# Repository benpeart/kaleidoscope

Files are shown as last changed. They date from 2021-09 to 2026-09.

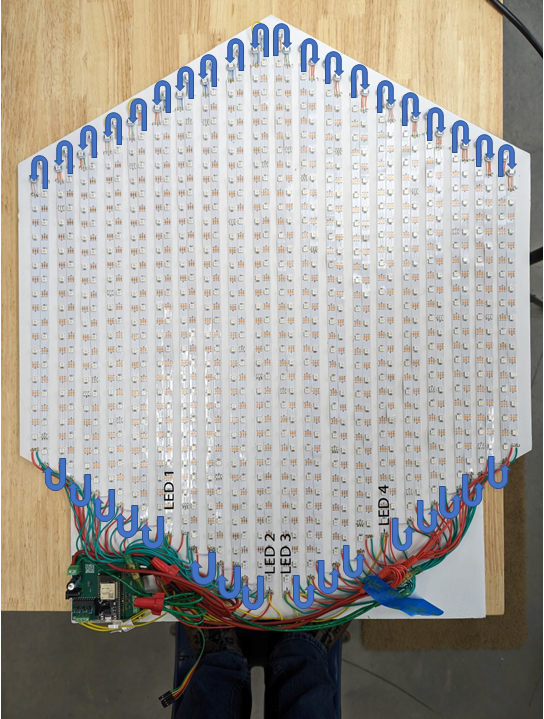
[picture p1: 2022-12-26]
images/Wiring diagram for LED strips.png

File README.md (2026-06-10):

# Kaleidoscope
A Digital Kaleidoscope maker project.

## Developer Workflow

Build the [env:release] image then flash the entire image (nvs, otadata, safeboot, app) with the command:

```
cd %userprofile%\.platformio\packages\tool-esptoolpy
python .\esptool.py write_flash 0x0 \src\kaleidoscope\.pio\build\release\firmware.factory.bin
```

Then connect to the KaleidoscopeAP with your phone and setup your WiFi credentials. Save and reboot and it will connect to your wifi with the name "kaleidoscope.local." Open http://kaleidoscope.local and configure the UI of the Kaleidoscope (mode, clock, reflection, brightness, speed, clock color).

Subsequent updates of the app partition can be updated using platform.io and the [env:release-ota] or [env:debug-ota] environments. You can also click the 'cloud upload' icon in the bottom left of the Kaleidoscope UI, refresh the page to load the safeboot ui, then drag/drop the firmware.bin file you want to flash

## User Workflow

### First Time Setup
1. Device starts without saved WiFi credentials
2. Fails to connect (timeout after 20 seconds)
3. Enters AP mode with SSID: `kaleidoscopeAP`
4. User connects their phone/computer to `kaleidoscopeAP`
5. Captive portal automatically opens (or user goes to `http://192.168.4.1`)
6. Configure WiFi SSID and password
7. Device saves credentials and reconnects
8. Kaleidoscope page becomes accessible at device's IP or `kaleidoscope.local`

### Subsequent Starts
1. Device boots and loads saved WiFi credentials
2. Connects to WiFi automatically
3. Kaleidoscope page immediately available

### OTA Update Process
1. User clicks cloud upload icon on the kaleidoscope page
2. Device reboots with SafeBoot partition active (refresh page to see)
3. Use the safeboot UI page to upload the new firmware
4. Device restarts with new firmware
5. If failure: SafeBoot recovery mechanism allows fallback

## REST API documentation

The Kaleidoscope connects to the WiFi with the device name "kaleidoscope." The web ui and REST API can be found at http://kaleidoscope.local/. 
Alternately, check your router for the IP address.

There are four REST endpoints that make up the REST API:

1. "http://kaleidoscope/api/settings"
1. "http://kaleidoscope/api/modes"
1. "http://kaleidoscope/api/faces"
1. "http://kaleidoscope/api/drawstyles"

## 'Settings' REST API

A GET sent to the Settings endpoint will return a result that includes the following entries:
PUT will allow you to set some or all of the same values.

```
{
    "mode": "Twinkle Fox",
    "drawStyle": "Six way",
    "brightness": 4095,
    "speed": 25,
    "clockFace": "Off",
    "clockColor": "#FFFFFF"
}
```

### Mode

The mode specifies which of the available Kaleidoscope modes is currently active. This can vary as more are added or removed but currently the list of available modes includes:

```
{
    "off",
    "Kaleidoscope",
    "Plasma",
    "Ripples",
    "Twinkle Fox",
    "AA Lines",
    "Distortion Waves",
    "Rainbow",
    "Matrix",
    "Pacifica",
    "Snake",
    "Fire"
}    
```        

### drawStyle

The drawStyle controls the type of reflection style the Kaleidoscope emulates. Currently this includes:

```
{
    "Six way",
    "Twelve way",
    "Twenty four way"
}
```        

### Brightness

Brightness is treated as an adjustment to the automatic brightness as computed using the photoresister to determine
the ambient brightness of the room. Greater than zero makes it brighter than default, less than zero makes it darker than default.
The valid range is -255 (dark) to 255 (bright). The default is 0.

### Speed

The Kaleidoscope speed is a value between 0 (slow) to 255 (fast). The default is 127.
Not all modes can honor all speeds; each one is responsible for making a 'best effort.'

### clockFace

Choose what clock face (if any) is displayed.

```
{
    "Off",
    "Digital",
    "Analog"
}
```

### clockColor

A hexadecimal color is specified with: #RRGGBB, where the RR (red), GG (green) and BB (blue) hexadecimal integers specify the components of the color.

## 'Modes' REST API

A GET sent to the /api/modes endpoint will return an array of the available modes.
PUT will allow you to set some or all of the same values.

A sample result would be the following:

```
["Kaleidoscope","Plasma","Ripples","Twinkle Fox","AA Lines","Distortion Waves","Rainbow","Matrix","Pacifica","Snake","Fire"]
```

## 'Faces' REST API

A GET sent to the /api/faces endpoint will return an array of the available clock faces.
PUT will allow you to set some or all of the same values.

A sample result would be the following:

```
["Off","Digital","Analog"]
```

## 'DrawStyles' REST API

A GET sent to the /api/drawstyles endpoint will return an array of the posible draw styles.
PUT will allow you to set some or all of the same values.

A sample result would be the following:

```
["Six way","Twelve way","Twenty four way"]
```

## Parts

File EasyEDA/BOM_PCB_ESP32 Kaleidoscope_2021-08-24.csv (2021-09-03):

ID | Name | Designator | Footprint | Quantity | Manufacturer Part | Manufacturer | Supplier | Supplier Part | Price | Pins | 3DModel | JLCPCB Part Class | LCSC Assembly | Paste Type | Contributor | SMT Type | description | link
1 | 10K | R5,R6,R7,R8,R9,R10,R11 | R0603 | 7 | ARG03FTC1002 | Viking Tech | LCSC | C217687 | 0.007 | 2 | R0603_L1.6-W0.8-H0.8 | Extended Part |  |  | LCSC |  |  | https://www.mouser.in/datasheet/2/447/PYu_RT_1_to_0_01_RoHS_L_11-1669912.pdf
2 | 1000uF | C1 | CAP-TH_BD10.0-P5.00-D1.0-FD | 1 | 25YXJ1000M10X20 | Rubycon | LCSC | C88720 | 0.271 | 2 | CAP-TH_D10.0-H16.0-P5.00 | Extended Part |  |  | 官方封装库 |  |  | https://item.szlcsc.com/44833.html
3 | 10nF | C2,C3,C4,C5,C6,C7 | CAP-TH_L5.0-W2.5-P2.54-D0.7 | 6 | CC1H103ZA1AD3F4D10MF | Dersonic | LCSC | C254082 | 0.013 | 2 | CAP-TH_BD5.0-W2.5-P2.54 | Extended Part |  |  | LCSC |  | Indicating Instrument; 2 Leads | https://lcsc.com/product-detail/Ceramic-Disc-Capacitors_Made-in-China-CS1F5-6Y5V1A104Z_C9306.html
4 | 470K | LED1,LED2,LED3,LED4 | R1206 | 4 | RMCF1206JT470K | Stackpole Elec | LCSC | C237785 | 0.012 | 2 | R1206_L3.2-W1.6-H0.6 | Extended Part |  |  | LCSC |  |  | https://item.szlcsc.com/311874.html
5 | SN74HCT245N | BUFFER1 | DIP-20_L26.8-W6.4-P2.54-LS7.6-BL | 1 | SN74HCT245N | Texas Instruments | LCSC | C133640 | 0.402 | 20 | DIP-20_L26.2-W6.4-H5.4-LS7.62-P2.54 |  |  |  | LCSC |  |  | https://item.szlcsc.com/348321.html
6 | WJ124-3.81-4P | P1 | CONN-TH_4P-P3.81_KF124-3.81-4P | 1 | WJ124-3.81-4P | ReliaPro | LCSC | C69809 | 0.348 | 4 | CONN-TH_WJ3.81-LI-4P-124 | Extended Part |  |  | 立创EDA官方封装库 |  |  | https://item.szlcsc.com/70903.html
7 | WJ128V-5.0-2P | P2 | CONN-TH_2P-P5.00_WJ128V-5.0-2P | 1 | WJ128V-5.0-2P | ReliaPro | LCSC | C8269 | 0.115 | 2 | CONN-TH_2P-L10.0-W10.3-H14.1-P5.0 | Extended Part |  |  | 立创EDA官方封装库 |  |  | https://item.szlcsc.com/8761.html
8 | RE-H022TD-1190 (LF)(SN) | PHOTO | HDR-TH_2P-P2.54-V | 1 | - | JST Sales America | LCSC | C160332 | 0.084 | 2 | HDR-M-2.54_1x2 |  | Yes | expand | LCSC | Extend |  | https://item.szlcsc.com/366904.html
9 | DC-470-2.1GP | DC_5V | DC-IN-TH_DC-470-2.1GP | 1 | DC-470-2.1GP | GANGYUAN | LCSC | C194407 | 0.055 | 3 | DC-IN-TH_L14.0-W8.9-H10.9 |  |  |  | 立创EDA官方封装库 |  |  | https://so.szlcsc.com/global.html?c=&k=C194407
10 | ESP32 - WROOM-32U - DevKit 38pins | U1 | ESP32 - WROOM-32U - DEVVKIT 38PIN | 1 |  |  | Sparkfun |  |  | 38 |  |  |  |  | chrisrisse
11 | WJ124-3.81-5P-14-00A | LEFT_ENCODER,RIGHT_ENCODER | CONN-TH_5P-P3.81_KF124-3.81-5P | 2 | WJ124-3.81-5P-14-00A | ReliaPro | LCSC | C72336 | 0.328 | 5 | CONN-TH_5P-P3.81_KF124-3.81-5P |  |  | expand | 立创EDA官方封装库 |  |  | https://item.szlcsc.com/70903.html

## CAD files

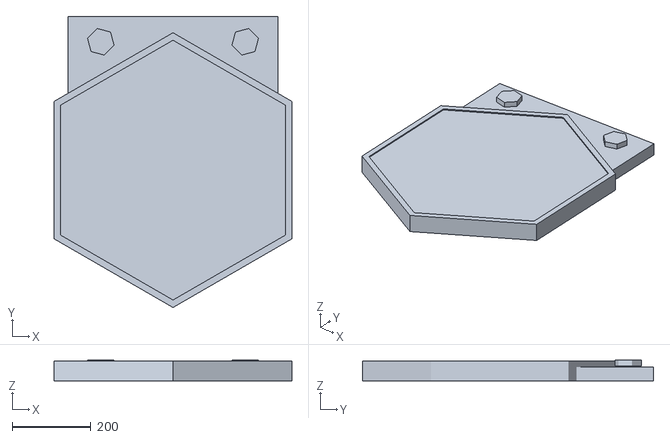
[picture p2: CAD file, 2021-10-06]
3dmodels/Kaleidoscope.stl
604.8 x 739.7 x 53.1

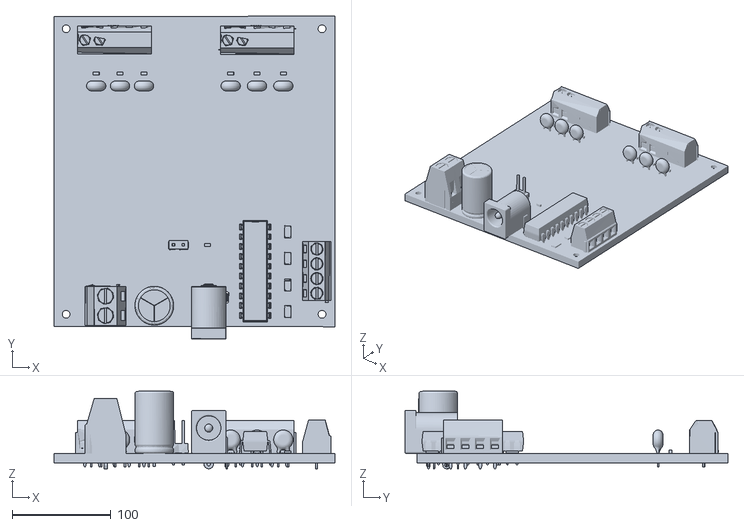
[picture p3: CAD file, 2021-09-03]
EasyEDA/OBJ_PCB_ESP32 Kaleidoscope.obj
285.2 x 327.6 x 78.7

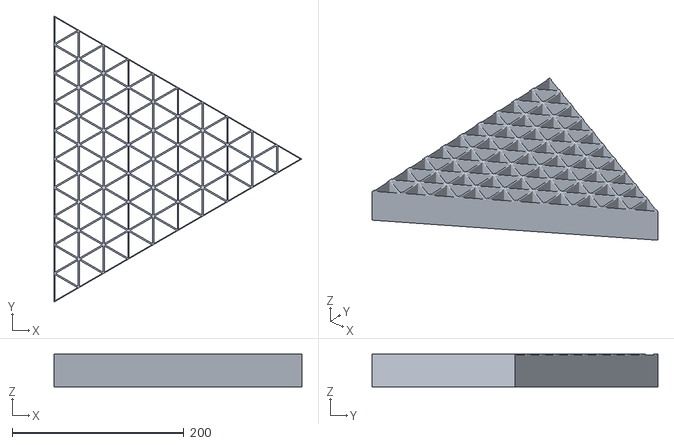
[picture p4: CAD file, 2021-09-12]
3dmodels/Honeycomb.stl
288.7 x 333.3 x 38.1

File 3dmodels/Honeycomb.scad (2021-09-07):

fudge=0.004;

// honeycomb dimensions
stroke = 2.4;
notch_width = 21;
notch_depth = 1;
distance_apart = 33 + 1/3;
wall_height = 38.1; // 1 1/2"
triangle_height = (distance_apart * sqrt(3)) / 2;
triangle_zaxis_offset=-fudge/2;
num_rings = 10;
radius = distance_apart * num_rings;

honeycomb();

module honeycomb()
{
    difference()
    {
        // draw the hexagon
        rotate(30) cylinder(h=wall_height, r=radius, $fn=6);
        
        // remove notches for the led strips
        for (i = [num_rings / 2 - 1:-1:(-2 * num_rings) + (num_rings / 2)]) // draws the square
        {
            orgin = [triangle_height * -10, distance_apart * i  + (triangle_height - notch_width) / 2, wall_height - notch_depth];
                                                                               //the + 1 is needed to finish the etch
            translate(orgin) rotate(30)cube([distance_apart * (num_rings * 2 + 1), notch_width,notch_depth]); 
        }
        
        // remove the triangles for the lights
        for (y = [num_rings:-1:-num_rings]) 
        {
            for (x = [-num_rings:2:num_rings])
            {
                translate([x * triangle_height + (triangle_height * (2/3)), y * distance_apart, triangle_zaxis_offset]) rotate(60) 
                    cylinder(h=wall_height+fudge, r=(triangle_height* 2/3) - stroke/2, $fn=3);
                translate([x * triangle_height - (triangle_height * (2/3)), y * distance_apart, triangle_zaxis_offset]) rotate(0)
                    cylinder(h=wall_height+fudge, r=(triangle_height* 2/3) - stroke/2, $fn=3);
                
                translate([(x+1) * triangle_height + (triangle_height * (2/3)), (y) * distance_apart + distance_apart / 2, triangle_zaxis_offset]) rotate(60) 
                    cylinder(h=wall_height+fudge, r=(triangle_height* 2/3) - stroke/2, $fn=3);
                translate([(x+1) * triangle_height - (triangle_height * (2/3)), (y) * distance_apart + distance_apart / 2, triangle_zaxis_offset]) rotate(0)
                    cylinder(h=wall_height+fudge, r=(triangle_height* 2/3) - stroke/2, $fn=3);        
            }
        }

        // shrink the size for testing purposes
        translate([0,0,-1]) rotate(60) cube([1000,1000,100]);
        translate([0,0,-1]) rotate(120) cube([1000,1000,100]);
        translate([0,0,-1]) rotate(180) cube([1000,1000,100]);
        translate([0,0,-1]) rotate(-0) cube([1000,1000,100]);
        translate([0,0,-1]) rotate(-30) cube([1000,1000,100]);
        /*
        translate([0,-8 * distance_apart,-1]) rotate(30) cube([1000,1000,100]);
        translate([0,-6 * distance_apart,-1]) rotate(-30) cube([1000,1000,100]);
        */

    }
}

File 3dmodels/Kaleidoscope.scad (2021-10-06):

fudge=0.004;

// honeycomb dimensions
stroke = 3.2;   // this needs to be double the wall width you actually want when printing, not sure why...
                // the printer can print in increments of 0.4 mm so we make the outside walls 0.8mm and the inside
                // walls 1.6mm.
notch_width = 21;
notch_depth = 1;
distance_apart = 33 + 1/3;
wall_height = 38.1; // 1 1/2"
triangle_height = (distance_apart * sqrt(3)) / 2;
triangle_zaxis_offset=-fudge/2;
num_rings = 10;
radius = distance_apart * num_rings;

// diffuser dimensions
diffuser_thickness = 3.175; // 1/8 inch

// backboard dimensions
backboard_thickness = 6.35; // 1/4 inch

// side wall dimensions
side_wall_thickness = 19.05;// 3/4 inch
side_wall_height = backboard_thickness + wall_height + (2 * diffuser_thickness);

// chin dimensions
chin_width = (radius + side_wall_thickness) * sin(60) * 2 - (4 * side_wall_thickness);
chin_depth = side_wall_thickness + wall_height;
chin_wall_height = 31.75; // 1 1/4 inch

// knob dimensions
knob_height = 15;
knob_radius = 35;


//
// Draw all the component pieces
//
color("yellow") backboard();
color("blue") honeycomb_sidewall();
//color("black") honeycomb();
color("gray", 0.25) diffuser();

color("brown") chin_sidewall();
//color("green") translate([-559 - side_wall_thickness, -770, backboard_thickness]) rotate(90) resize([72.8, 80.4, 25]) import("OBJ_PCB_ESP32 Kaleidoscope.stl");
color("brown", 0.5) chin_top();

color("silver") translate([chin_width / 4 + 50, radius - chin_depth + 50, chin_wall_height + backboard_thickness]) rotate(15) cylinder(h=knob_height, r=knob_radius, $fn=6);
color("silver") translate([-(chin_width / 4 + 50), radius - chin_depth + 50, chin_wall_height + backboard_thickness]) rotate(45) cylinder(h=knob_height, r=knob_radius, $fn=6);


module backboard()
{
    union()
    {
        // draw the hexagon
        rotate(30)
        cylinder(h=backboard_thickness, r=(radius + diffuser_thickness), $fn=6);
        
        // draw the chin
        translate([side_wall_thickness - chin_width / 2 - diffuser_thickness, chin_depth + side_wall_thickness, 0])
        cube([chin_width - (2 * side_wall_thickness) + (2 *  + diffuser_thickness), radius - (2 * side_wall_thickness) + diffuser_thickness, backboard_thickness]);
    }
}

module diffuser()
{
    // draw the diffuser hexagon
    rotate(30)
    translate([0, 0, backboard_thickness + wall_height]) 
    cylinder(h=diffuser_thickness, r=(radius + diffuser_thickness), $fn=6);
}

module honeycomb_sidewall()
{
    rotate(30)
    difference()
    {
        // draw the expanded hexagon
        cylinder(h=side_wall_height, r=(radius + side_wall_thickness - diffuser_thickness), $fn=6);

        // now remove the face of the honeycomb leaving a lip to hold the contents (diffuser + honeycomb + backboard)
        translate([0, 0, -fudge / 2]) 
        cylinder(h=side_wall_height + fudge, r=radius - diffuser_thickness, $fn=6);

        // now remove bottom of the honeycomb to leave room for the diffuser, honeycomb and backboard
        translate([0, 0, -diffuser_thickness]) 
        cylinder(h=side_wall_height, r=radius, $fn=6);
        
        // remove the chin in two pieces to leave a support
        rotate(-30)
        translate([-chin_width / 2, chin_depth, -fudge/2]) 
        cube([chin_width / 2 - 10, radius, chin_wall_height + diffuser_thickness + fudge]);
        rotate(-30)
        translate([10, chin_depth, -fudge/2]) 
        cube([chin_width / 2 - 10, radius, chin_wall_height + diffuser_thickness + fudge]);
    }
}

module chin_sidewall()
{
    difference()
    {
        // draw the chin
        translate([-chin_width / 2, chin_depth, 0]) 
        cube([chin_width, radius, chin_wall_height]);
        
        // remove the chin insides
        translate([-chin_width / 2 + side_wall_thickness, chin_depth, - fudge / 2]) 
        cube([chin_width - (2 * side_wall_thickness), radius - side_wall_thickness, chin_wall_height + fudge]);

        // remove the expanded hexagon
        rotate(30) translate([0, fudge / 2, 0]) 
        cylinder(h=side_wall_height + fudge, r=radius, $fn=6);
        
        // remove a notch for the backboard
        backboard();
    }
}

module chin_top()
{
    difference()
    {
        // draw a lid for the chin
        translate([-chin_width / 2, chin_depth, chin_wall_height]) 
        cube([chin_width, radius, diffuser_thickness]);
        
        // remove the expanded hexagon
        rotate(30) translate([0, fudge / 2, 0]) 
        cylinder(h=side_wall_height + fudge, r=radius, $fn=6);
    }
}

module honeycomb()
{
    translate([0, 0, backboard_thickness]) 
    difference()
    {
        // draw the hexagon
        rotate(30) cylinder(h=wall_height, r=radius, $fn=6);
        
        // remove notches for the led strips
        for (i = [num_rings / 2 - 1:-1:(-2 * num_rings) + (num_rings / 2)]) // draws the square
        {
            orgin = [triangle_height * -10, distance_apart * i  + (triangle_height - notch_width) / 2, wall_height - notch_depth];
                                                                               //the + 1 is needed to finish the etch
            translate(orgin) rotate(30)cube([distance_apart * (num_rings * 2 + 1), notch_width,notch_depth]); 
        }
        
        // remove the triangles for the lights
        for (y = [num_rings:-1:-num_rings]) 
        {
            for (x = [-num_rings:2:num_rings])
            {
                translate([x * triangle_height + (triangle_height * (2/3)), y * distance_apart, triangle_zaxis_offset]) rotate(60) 
                    cylinder(h=wall_height+fudge, r=(triangle_height* 2/3) - stroke/2, $fn=3);
                translate([x * triangle_height - (triangle_height * (2/3)), y * distance_apart, triangle_zaxis_offset]) rotate(0)
                    cylinder(h=wall_height+fudge, r=(triangle_height* 2/3) - stroke/2, $fn=3);
                
                translate([(x+1) * triangle_height + (triangle_height * (2/3)), (y) * distance_apart + distance_apart / 2, triangle_zaxis_offset]) rotate(60) 
                    cylinder(h=wall_height+fudge, r=(triangle_height* 2/3) - stroke/2, $fn=3);
                translate([(x+1) * triangle_height - (triangle_height * (2/3)), (y) * distance_apart + distance_apart / 2, triangle_zaxis_offset]) rotate(0)
                    cylinder(h=wall_height+fudge, r=(triangle_height* 2/3) - stroke/2, $fn=3);        
            }
        }
        // shrink the size for testing purposes
        translate([0,0,-1]) rotate(60) cube([1000,1000,100]);
        translate([0,0,-1]) rotate(120) cube([1000,1000,100]);
        translate([0,0,-1]) rotate(180) cube([1000,1000,100]);
        translate([0,0,-1]) rotate(-0) cube([1000,1000,100]);
        translate([0,0,-1]) rotate(-30) cube([1000,1000,100]);
/*
        translate([0,-4 * distance_apart,-1]) rotate(30) cube([1000,1000,100]);
        translate([0,-4 * distance_apart,-1]) rotate(-30) cube([1000,1000,100]);
*/
    }
}

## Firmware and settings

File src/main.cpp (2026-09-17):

#include "main.h"
#include "debug.h"
#include "settings.h"
#include "modes.h"
#include <math.h>
#include "DoubleResetDetector.h"
#include <MycilaSystem.h>

#ifdef BOUNCE
// https://github.com/thomasfredericks/Bounce2
#include <Bounce2.h>
#endif // BOUNCE

#ifdef WIFI
#include "WiFiHelpers.h"

#ifdef REST
#include <AsyncJson.h>
#endif // REST

#ifdef TIME
#include "RealTimeClock.h"
#endif // TIME

#ifdef WEATHER
#include "weather.h"
#endif // WEATHER

#endif // WIFI

//
// GLOBAL PIN DECLARATIONS -------------------------------------------------
//
#ifdef PHOTOCELL
#define PHOTOCELL_PIN 33
#endif

#ifdef ENCODER
// Change these pin numbers to the pins connected to your encoder.
#define ENCODER_CLK_PIN_LEFT 4
#define ENCODER_DT_PIN_LEFT 16
#define ENCODER_CLK_PIN_RIGHT 5
#define ENCODER_DT_PIN_RIGHT 18
#endif

#ifdef BOUNCE
// Change these pin numbers to the button pins on your encoder.
#define ENCODER_SW_PIN_LEFT 17
#define ENCODER_SW_PIN_RIGHT 19
#endif // BOUNCE

// setup our LED strips for parallel output using FastLED
#ifdef JTAG
// JTAG uses GPIO12-GPIO15 so we can't use GPIO14 for an LED strip. Redefine it to use an unused GPIO
// so that we can debug even though we can't see the output of LED_STRIP_PIN_1 when mounted on the PCB.
// TODO: when we rev the PCB, use a different GPIO for LED_STRIP_PIN_1
#define LED_STRIP_PIN_1 32
#else
#define LED_STRIP_PIN_1 14
#endif
#define LED_STRIP_PIN_2 27
#define LED_STRIP_PIN_3 26
#define LED_STRIP_PIN_4 25
#define LED_TYPE WS2812B
#define COLOR_ORDER GRB

//
// Global variables  -------------------------------------------------
//

DoubleResetDetector drd(&preferences);

#ifdef BOUNCE
// Instantiate Button objects from the Bounce2 namespace
Bounce2::Button leftButton = Bounce2::Button();
Bounce2::Button rightButton = Bounce2::Button();
#define DEBOUNCE_MS 15 // Button debounce time, in milliseconds
#endif

#ifdef ENCODER
// Instantiate rotary encoder knob objects
ESP32Encoder knobRight;
ESP32Encoder knobLeft;
#endif

//
// BRIGHTNESS helpers -------------------------------------------------
//

// true if the brightness has been changed via the REST API and needs to be reflected immediately
volatile bool brightness_dirty = false;

// Tracks the next Unix timestamp (epoch seconds) when brightness needs recalculation.
// Checking once every 15 to 30 seconds only while in twilight, and setting the next wake
// time to the exact start of the next twilight when outside it, drops checks from ~28,000 down to
// roughly ~250 per day.
static time_t nextSolarCheckEpoch = 0;

// Transition window duration in minutes (e.g., 60 mins total: 30 mins before, 30 mins after dawn/dusk)
#define TWILIGHT_TRANSITION_MINUTES 60.0f

#define KNOB_INCREMENT (MAX_BRIGHTNESS / 20) // brightness range / number of pulses in one rotation of rotary encoder

// Returns a smooth multiplier from 0.5 (full night) to 1.0 (full day) and schedules next check
float getSolarBrightnessScale()
{
#if defined(TIME)
  time_t now = time(nullptr);
  if (now < 100000)
  {
    // Fallback if clock is not synchronized yet; recheck in 10s
    nextSolarCheckEpoch = now + 10;
    return 1.0f;
  }

  struct tm local_tm;
  struct tm utc_tm;
  localtime_r(&now, &local_tm);
  gmtime_r(&now, &utc_tm);

  int N = local_tm.tm_yday + 1;

  // Solar declination (radians)
  float declination = 0.4093f * sin(2.0f * M_PI * (284 + N) / 365.0f);
  float latRad = currentLatitude * (M_PI / 180.0f);

  // Hour angle for standard zenith
  float cosOmega = -tan(latRad) * tan(declination);

  if (cosOmega >= 1.0f)
  {
    // Polar night: check again in an hour
    nextSolarCheckEpoch = now + 3600;
    return 0.5f;
  }
  if (cosOmega <= -1.0f)
  {
    // Midnight sun: check again in an hour
    nextSolarCheckEpoch = now + 3600;
    return 1.0f;
  }

  float omega = acos(cosOmega) * (180.0f / M_PI);

  // Solar noon adjusted for UTC offset
  time_t local_sec = mktime(&local_tm);
  time_t utc_sec = mktime(&utc_tm);
  float gmtOffsetHours = (float)difftime(local_sec, utc_sec) / 3600.0f;
  float solarNoon = 12.0f - (currentLongitude / 15.0f) + gmtOffsetHours;

  float dawnHour = solarNoon - (omega / 15.0f);
  float duskHour = solarNoon + (omega / 15.0f);

  // Local time in fractional hours
  float currentHour = local_tm.tm_hour + (local_tm.tm_min / 60.0f) + (local_tm.tm_sec / 3600.0f);

  float halfWindowHours = (TWILIGHT_TRANSITION_MINUTES / 60.0f) / 2.0f;
  float dawnStart = dawnHour - halfWindowHours;
  float dawnEnd = dawnHour + halfWindowHours;
  float duskStart = duskHour - halfWindowHours;
  float duskEnd = duskHour + halfWindowHours;

  float dayFactor = 0.0f;

  if (currentHour >= dawnEnd && currentHour < duskStart)
  {
    // Full daylight: schedule wake-up exactly when dusk transition begins
    dayFactor = 1.0f;
    float secondsUntilDusk = (duskStart - currentHour) * 3600.0f;
    nextSolarCheckEpoch = now + (time_t)max(1.0f, secondsUntilDusk);
  }
  else if (currentHour >= duskEnd || currentHour < dawnStart)
  {
    // Full night: schedule wake-up exactly when dawn transition begins
    dayFactor = 0.0f;
    float hoursUntilDawn = (currentHour < dawnStart) ? (dawnStart - currentHour)
                                                     : (24.0f - currentHour + dawnStart);
    nextSolarCheckEpoch = now + (time_t)max(1.0f, hoursUntilDawn * 3600.0f);
  }
  else
  {
    // In active twilight transition: step every 15s (captures single-unit changes at max slope)
    nextSolarCheckEpoch = now + 15;

    if (currentHour < dawnEnd)
    {
      // Dawn window: ramping UP (night -> day)
      float progress = (currentHour - dawnStart) / (2.0f * halfWindowHours);
      dayFactor = 0.5f * (1.0f - cos(constrain(progress, 0.0f, 1.0f) * M_PI));
    }
    else
    {
      // Dusk window: ramping DOWN (day -> night)
      float progress = (currentHour - duskStart) / (2.0f * halfWindowHours);
      dayFactor = 0.5f * (1.0f + cos(constrain(progress, 0.0f, 1.0f) * M_PI));
    }
  }

  // Scale: 0.5 (night) to 1.0 (day)
  return 0.5f + (0.5f * dayFactor);
#else
  return 1.0f;
#endif
}

// manually adjust the brightness offset via the rotary encoder
int manualBrightness(bool useKnob)
{
  if (!useKnob)
    return settings.brightness;

#ifdef ENCODER
  // use the right knob as a brightness increment/decrement
  static int lastRightKnob = 0;
  int knob = knobRight.getCount();
  if (knob != lastRightKnob)
  {
    if (knob > lastRightKnob)
      settings.brightness -= KNOB_INCREMENT;
    else
      settings.brightness += KNOB_INCREMENT;

    settings.brightness = constrain(settings.brightness, MIN_BRIGHTNESS, MAX_BRIGHTNESS);
    lastRightKnob = knob;

    DB_PRINTF("brightness = %d\r\n", settings.brightness);
  }
#ifdef DEBUG
  // test code for the left knob
  static int lastLeftKnob = 0;
  knob = knobLeft.getCount();
  if (knob != lastLeftKnob)
  {
    lastLeftKnob = knob;
    DB_PRINTF("Left knob count = %d\r\n", lastLeftKnob);
  }
#endif // DEBUG
#endif // ENCODER

  return settings.brightness;
}

//
// NOTE: adjustBrightness and adjustSpeed are currently called from the individual
// modes as each mode may want to do something different with the knobs (ie the 'snake' mode)
//

// update the FastLED brightness based on getSolarBrightnessScale and settings
void adjustBrightness(bool useKnob)
{
  manualBrightness(useKnob);

  static int LEDbrightness = 0;
  time_t now = time(nullptr);

  // Recompute immediately if:
  // 1. Encoder knob was turned (useKnob)
  // 2. REST API modified settings (brightness_dirty)
  // 3. Next scheduled recalculation time has arrived
  if (useKnob || brightness_dirty || (now >= nextSolarCheckEpoch))
  {
    brightness_dirty = false;

    int newBrightness = constrain((int)round(settings.brightness * getSolarBrightnessScale()), MIN_BRIGHTNESS, MAX_BRIGHTNESS);
    if (newBrightness != LEDbrightness)
    {
      LEDbrightness = newBrightness;
      DB_PRINTF("new brightness = %d\r\n", newBrightness);

      FastLED.setBrightness(dim8_raw(LEDbrightness));
      leds_dirty = true;
    }
  }
}

//
// use the left rotary knob to adjust the speed of the kaleidoscope
//

// The increment is defined to require two complete knob rotations to go from min to max
// Each knob roration is 20 clicks.
#define INCREMENT_SPEED (MAX_SPEED / 40)
int adjustSpeed()
{
#ifdef ENCODER
  static int lastLeftKnob = 0;
  int new_speed = settings.speed;

  int knob = knobLeft.getCount();
  if (knob != lastLeftKnob)
  {
    if (knob > lastLeftKnob)
      new_speed -= INCREMENT_SPEED;
    else
      new_speed += INCREMENT_SPEED;

    settings.speed = constrain(new_speed, 0, MAX_SPEED);
    lastLeftKnob = knob;

    DB_PRINTF("ms between frames = %d\r\n", settings.speed);
  }
#endif
  return settings.speed;
}

#ifdef REST
void saveSettings(AsyncWebServerRequest *request, JsonVariant &json)
{
  const JsonObject &jsonObj = json.as<JsonObject>();

  DB_PRINTLN("REST saveSettings:");

  // update the brightness (if it was passed)
  JsonVariant brightness = jsonObj["brightness"];
  if (!brightness.isNull())
  {
    settings.brightness = constrain((int)brightness, MIN_BRIGHTNESS, MAX_BRIGHTNESS);
    brightness_dirty = true; // Triggers immediate adjustment in loop
    DB_PRINTF("  brightness = %d\r\n", settings.brightness);
  }

  JsonVariant speed = jsonObj["speed"];
  if (!speed.isNull())
  {
    settings.speed = constrain((int)speed, 0, MAX_SPEED);
    DB_PRINTF("  speed = %d\r\n", settings.speed);
  }

  const char *modeName = jsonObj["mode"];
  if (modeName)
  {
    for (int x = 0; x < kaleidoscopeModes; x++)
    {
      if (String(KaleidoscopeModeLUT[x].modeName).equalsIgnoreCase(String(modeName)))
      {
        setKaleidoscopeMode(x);
        DB_PRINTF("  mode = %s\r\n", KaleidoscopeModeLUT[x].modeName);
        break;
      }
    }
  }

  const char *drawStyle = jsonObj["drawStyle"];
  if (drawStyle)
  {
    for (int x = 0; x < N_DRAW_STYLES; x++)
    {
      if (String(drawStylesLUT[x]).equalsIgnoreCase(String(drawStyle)))
      {
        setDrawStyle(x);
        DB_PRINTF("  drawStyle = %s\r\n", drawStylesLUT[x]);
        break;
      }
    }
  }

#ifdef TIME
  const char *clockFace = jsonObj["clockFace"];
  if (clockFace)
  {
    for (int x = 0; x < clockFaces; x++)
    {
      if (String(clockFaceLUT[x].faceName).equalsIgnoreCase(String(clockFace)))
      {
        setClockFace(x);
        DB_PRINTF("  clockFace = %s\r\n", clockFaceLUT[x].faceName);
        break;
      }
    }
  }

  JsonVariant clockColor = jsonObj["clockColor"];
  if (!clockColor.isNull())
  {
    uint32_t color;

    sscanf(clockColor, "#%06X", &color);
    settings.clockColor = CRGB(color);
    DB_PRINTF("  clockColor = #%06X\r\n", settings.clockColor.r << 16 | settings.clockColor.g << 8 | settings.clockColor.b);
  }
#endif // TIME

  request->send(200, "text/plain", "OK");
}

void getSettings(AsyncWebServerRequest *request)
{
  JsonDocument doc;
  String response;

  doc["mode"] = KaleidoscopeModeLUT[settings.mode].modeName;
  doc["drawStyle"] = drawStylesLUT[settings.drawStyle];
  doc["brightness"] = settings.brightness;
  doc["speed"] = settings.speed;
#ifdef TIME
  doc["clockFace"] = clockFaceLUT[settings.clockFace].faceName;
  char color[8];
  sprintf(color, "#%06X", settings.clockColor.r << 16 | settings.clockColor.g << 8 | settings.clockColor.b);
  doc["clockColor"] = color;
#endif // TIME

  serializeJson(doc, response);
  DB_PRINTLN("REST getSettings: " + response);
  request->send(200, "text/json", response);
}

void getModes(AsyncWebServerRequest *request)
{
  // allocate the memory for the document
  JsonDocument doc;

  // create an empty array
  JsonArray array = doc.to<JsonArray>();

  // add the names
  for (int x = 0; x < kaleidoscopeModes; x++)
  {
    if (KaleidoscopeModeLUT[x].showInRESTAPI)
      array.add(KaleidoscopeModeLUT[x].modeName);
  }

  // serialize the array and send the result
  String response;
  serializeJson(doc, response);
  DB_PRINTLN("REST getModes: " + response);
  request->send(200, "text/json", response);
}

#ifdef TIME
void getFaces(AsyncWebServerRequest *request)
{
  // allocate the memory for the document
  JsonDocument doc;

  // create an empty array
  JsonArray array = doc.to<JsonArray>();

  // add the names
  for (int x = 0; x < clockFaces; x++)
  {
    array.add(clockFaceLUT[x].faceName);
  }

  // serialize the array and send the result
  String response;
  serializeJson(doc, response);
  DB_PRINTLN("REST getFaces: " + response);
  request->send(200, "text/json", response);
}
#endif // TIME

void getDrawStyles(AsyncWebServerRequest *request)
{
  // allocate the memory for the document
  JsonDocument doc;

  // create an empty array
  JsonArray array = doc.to<JsonArray>();

  // add the draw style names
  for (int x = 0; x < N_DRAW_STYLES; x++)
  {
    array.add(drawStylesLUT[x]);
  }

  // serialize the array and send the result
  String response;
  serializeJson(doc, response);
  DB_PRINTLN("REST getDrawStyles: " + response);
  request->send(200, "text/json", response);
}

#endif // REST

//
// SETUP FUNCTION -- RUNS ONCE AT PROGRAM START ----------------------------
//

void setup()
{
#ifdef DEBUG
  Serial.begin(921600);
  Serial.setTimeout(2); // Fail-safe: prevent any blocking stream reads

  // Bounded startup check: do not block indefinitely if host is absent or rebooting
  unsigned long startWait = millis();
  while (!Serial && (millis() - startWait < 1500))
    ;

  DB_PRINTLN("\nStarting Kaleidoscope on " + String(ARDUINO_BOARD));

  // Debug info about the ESP32 we are running on
  DB_PRINTF("ESP32 Chip Model: %s\r\n", ESP.getChipModel());
  DB_PRINTF("ESP32 Chip Revision: %u\r\n", ESP.getChipRevision());
  DB_PRINTF("ESP32 Chip Cores: %d\r\n", ESP.getChipCores());
  DB_PRINTF("ESP32 CPU Frequency: %d MHz\r\n", ESP.getCpuFreqMHz());
  DB_PRINTF("ESP32 Flash Size: %d MB\r\n", ESP.getFlashChipSize() / (1024 * 1024));
  DB_PRINTF("ESP32 Flash Speed: %d MHz\r\n", ESP.getFlashChipSpeed() / 1000000);
  DB_PRINTF("ESP32 PSRAM Size: %d MB\r\n", ESP.getPsramSize() / (1024 * 1024));
  DB_PRINTF("ESP32 Free PSRAM: %d MB\r\n", ESP.getFreePsram() / (1024 * 1024));
#endif

  // initialize the settings from persistent storage
  settingsSetup();

  // Initialize the double reset detector
  drd.setup();

#ifdef WIFI
  // connect to wifi or enter AP mode so it can be configured
  wifi_setup();

#ifdef REST
  // setup the REST API endpoints and handlers
  webServer.on("/api/settings", HTTP_GET, getSettings);
  AsyncCallbackJsonWebHandler *handler = new AsyncCallbackJsonWebHandler("/api/settings", saveSettings);
  webServer.addHandler(handler);
  webServer.on("/api/modes", HTTP_GET, getModes);
#ifdef TIME
  webServer.on("/api/faces", HTTP_GET, getFaces);
#endif // TIME
  webServer.on("/api/drawstyles", HTTP_GET, getDrawStyles);
#endif
#endif // WIFI

#ifdef PHOTOCELL
  // Testing shows that the internal pullup resistors on the ESP32 are complete crap and
  // unusable. Probably why every example does their own external pullup/down resistors.
  pinMode(PHOTOCELL_PIN, INPUT /*_PULLUP*/);
#endif

  randomSeed(esp_random()); // Get a random number from the hardware RNG

#ifdef BOUNCE
  // initialize the rotary encoder switches. The KY-040 rotary encoders already contain
  // 10k-Ohm pull up resisters so we don't need to turn on the internal ones
  leftButton.attach(ENCODER_SW_PIN_LEFT, INPUT);
  leftButton.interval(DEBOUNCE_MS);
  leftButton.setPressedState(LOW);
  rightButton.attach(ENCODER_SW_PIN_RIGHT, INPUT);
  rightButton.interval(DEBOUNCE_MS);
  rightButton.setPressedState(LOW);
#endif

#ifdef ENCODER
  // Initialize the rotary encoders. The KY-040 rotary encoders already contain
  // 10k-Ohm pull up resisters so we don't need to turn on the internal ones
  ESP32Encoder::useInternalWeakPullResistors = puType::none;
  knobRight.attachSingleEdge(ENCODER_CLK_PIN_RIGHT, ENCODER_DT_PIN_RIGHT);
  knobRight.setFilter(1023);
  knobLeft.attachSingleEdge(ENCODER_CLK_PIN_LEFT, ENCODER_DT_PIN_LEFT);
  knobLeft.setFilter(1023);
#endif

  // intialize the LED strips for parallel output
  FastLED.addLeds<LED_TYPE, LED_STRIP_PIN_1, COLOR_ORDER>(leds + 0 * NUM_LEDS_PER_STRIP, NUM_LEDS_PER_STRIP).setCorrection(TypicalLEDStrip);
  FastLED.addLeds<LED_TYPE, LED_STRIP_PIN_2, COLOR_ORDER>(leds + 1 * NUM_LEDS_PER_STRIP, NUM_LEDS_PER_STRIP).setCorrection(TypicalLEDStrip);
  FastLED.addLeds<LED_TYPE, LED_STRIP_PIN_3, COLOR_ORDER>(leds + 2 * NUM_LEDS_PER_STRIP, NUM_LEDS_PER_STRIP).setCorrection(TypicalLEDStrip);
  FastLED.addLeds<LED_TYPE, LED_STRIP_PIN_4, COLOR_ORDER>(leds + 3 * NUM_LEDS_PER_STRIP, NUM_LEDS_PER_STRIP).setCorrection(TypicalLEDStrip);
  leds_dirty = true;
  DB_PRINTLN(KaleidoscopeModeLUT[settings.mode].modeName);
}

//
// LOOP FUNCTION -- RUNS OVER AND OVER FOREVER -----------------------------
//
void loop()
{
  // check for a double reset where we should enter safeboot mode
  drd.loop();
  if (drd.isDoubleReset())
  {
    DB_PRINTLN("Double reset detected, entering SafeBoot mode...");
    preferences.end();
    Mycila::System::restartFactory("safeboot");
  }

#ifdef WIFI
  // check that WiFi is still connected and reconnect if necessary
  wifi_loop();

  // if we get an updated location, force a solar brightness recalculation
  static bool locationUpdated = false;
  if (locationAcquired && !locationUpdated)
  {
    locationUpdated = true;
    nextSolarCheckEpoch = 0;
  }
#endif // WIFI

#ifdef BOUNCE
  // Left button pressed?
  leftButton.update();
  if (leftButton.pressed())
    previousKaleidoscopeMode();

  // Right button pressed?
  rightButton.update();
  if (rightButton.pressed())
    nextKaleidoscopeMode();
#endif

  if (eraseLEDs)
  {
    // clear the LED strips before drawing the new mode
    FastLED.clear(true);
    leds_dirty = true;
    eraseLEDs = false;
  }

  // Render one frame in current mode. To control the speed of updates, use the
  // EVERY_N_MILLISECONDS(N) macro to only update the frame when it is needed.
  // Also be sure to set leds_dirty = true so that the updated frame will be displayed.
  KaleidoscopeModeLUT[settings.mode].renderFunc();

#ifdef TIME
  // if the frame has been updated, overlay the clock face (can be a null clock face - see mode_select_clock_face())
  if ((KaleidoscopeModeLUT[settings.mode].renderFunc != mode_off) && leds_dirty)
    clockFaceLUT[settings.clockFace].renderFunc();
#endif // TIME

#ifdef WEATHER
  if (WiFi.status() == WL_CONNECTED)
    weather_loop(current_weather);
#endif // WEATHER

// Show an activity spinner and the current fps. After 500 ms of no LED updates show 0 fps.
// This is to prevent the fps flickering between 0 fps and x fps when there are no updates
// to display (i.e. not calling FastLED.Show every loop).
#ifdef DEBUG_FPS
  static CEveryNMilliseconds triggerTimer(500);
  static const char *spinner = "|/-\\";
  static int spinner_index = 0;

  if (leds_dirty)
  {
    DB_PRINTF("\r%c %d fps\r", spinner[spinner_index], FastLED.getFPS());
    spinner_index = (spinner_index + 1) % sizeof(spinner);
    triggerTimer.reset();
  }
  else
  {
    if (triggerTimer)
    {
      DB_PRINT("\r0 fps   \r");
    }
  }
#endif

  // if we have changes in the LEDs, show the updated frame
  if (leds_dirty)
  {
// #define DEBUG_SPINNER
#ifdef DEBUG_SPINNER
    static const char *spinner = "|/-\\";
    static int spinner_index = 0;

    DB_PRINTF("\r%c", spinner[spinner_index]);
    spinner_index = (spinner_index + 1) % sizeof(spinner);
#endif                  // DEBUG_SPINNER
    leds_dirty = false; // clear the dirty flag before showing the frame or changes via asyncronous REST calls will fail to be drawn
    FastLED.show();
  }

  // persist any changes to the settings
  EVERY_N_SECONDS(5)
  {
    settingsPersist();
  }
}

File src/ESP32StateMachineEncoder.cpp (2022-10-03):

/*
 * ESP32StateMachineEncoder.cpp
 *
 *  Based on Oleg Mazurov's code for rotary encoder interrupt service routines for AVR micros
 *  here https://chome.nerpa.tech/mcu/reading-rotary-encoder-on-arduino/ and using interrupts 
 *  https://chome.nerpa.tech/mcu/rotary-encoder-interrupt-service-routine-for-avr-micros/
 */
#ifdef STATEMACHINEENCODER
#include <ESP32StateMachineEncoder.h>

enum puType ESP32Encoder::useInternalWeakPullResistors = DOWN;

ESP32Encoder::ESP32Encoder()
{
    attached = false;
    aPinNumber = 0;
    bPinNumber = 0;
    count = 0;
    old_AB = 3; // Lookup table index
    encval = 0; // Encoder value
}

ESP32Encoder::~ESP32Encoder()
{
    detachInterrupt(aPinNumber);
    detachInterrupt(bPinNumber);
};

// Encoder interrupt routine for both pins. Updates counter
// if they are valid and have rotated a full indent
void IRAM_ATTR ESP32Encoder::read_encoder(void *arg)
{
    ESP32Encoder *ptr = (ESP32Encoder *)arg;

    static const int8_t enc_states[] = {0, -1, 1, 0, 1, 0, 0, -1, -1, 0, 0, 1, 0, 1, -1, 0}; // Lookup table

    ptr->old_AB <<= 2; // Remember previous state

    if (digitalRead(ptr->aPinNumber))
        ptr->old_AB |= 0x02; // Add current state of pin A
    if (digitalRead(ptr->bPinNumber))
        ptr->old_AB |= 0x01; // Add current state of pin B

    ptr->encval += enc_states[(ptr->old_AB & 0x0f)];

    // Update counter if encoder has rotated a full indent, that is at least 4 steps
    if (ptr->encval > 3)
    {                 // Four steps forward
        ptr->count--; // Decrease counter to match behavior of ESP32Encoder
        ptr->encval = 0;
    }
    else if (ptr->encval < -3)
    {                 // Four steps backwards
        ptr->count++; // Increase counter to match behavior of ESP32Encoder
        ptr->encval = 0;
    }
}

void ESP32Encoder::attachSingleEdge(uint8_t aPin, uint8_t bPin)
{
    if (attached)
        return;

    aPinNumber = aPin;
    bPinNumber = bPin;

    // Set encoder pins and attach interrupts
    switch (useInternalWeakPullResistors)
    {
    case UP:
        pinMode(aPinNumber, INPUT_PULLUP);
        pinMode(bPinNumber, INPUT_PULLUP);
        break;

    case DOWN:
        pinMode(aPinNumber, INPUT_PULLDOWN);
        pinMode(bPinNumber, INPUT_PULLDOWN);
        break;

    default:
        pinMode(aPinNumber, INPUT);
        pinMode(bPinNumber, INPUT);
        break;
    }
    attachInterruptArg(aPinNumber, read_encoder, this, CHANGE);
    attachInterruptArg(bPinNumber, read_encoder, this, CHANGE);
    attached = true;
}

int64_t ESP32Encoder::getCount()
{
    noInterrupts();
    int64_t ret = count;
    interrupts();
    return ret;
}

int64_t ESP32Encoder::clearCount()
{
    noInterrupts();
    count = 0;
    interrupts();
    return 0;
}

void ESP32Encoder::setCount(int64_t value)
{
    noInterrupts();
    count = value;
    interrupts();
}
#endif // STATEMACHINEENCODER

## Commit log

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2021-04-09 Refactor the Kaleidoscope.ino file to prepare for more program logic to handle the different 'modes' that we will need to be in.
    Create a new Kaleidoscope class to encapsulate the display of the Kaleidoscope.
    This required me to rename the Kaleidoscope.ino file as behind the scenes,
    they must generate a Kaleidoscope.h header file which conflicted with
    my new class header file.
    Create a new LEDStrips class to encapsulate the LED strips. Note, this
    would have been better as a singleton class but the Arduino tools apparently
    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
2021-04-11 Add support for various 'modes' (ie off, screensaver, kaleidoscope, etc). Each call to the function should render a single 'frame' and then return. It should not 'show' the frame - the outer program 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
    Add initial (not working yet as I don't have the rotary encoders yet)
    support for using the rotary encoder push buttons to switch between
    various modes. They will debounce any input and switch between the different
    program modes. When the left button is pressed, it moves to the next mode.
    The right switch moves to the previous mode.
2021-04-11 Add debug support. Two macros DB_PRINT and DB_PRINTLN map to Serial.print and Serial.println when DEBUG is defined. If it is not defined, they map to nothing.
2021-04-11 Refactor LEDs global variable to be named leds for consistency with the other globals.
2021-04-12 Update mode_rainbow* to only draw one frame per invocation so they work properly in the new architecture.
2021-04-13 Add support for two rotary encoders with buttons.
    Pressing the left button will go to the prior mode and the right button
    will advance to the next mode.
    The rotary knobs just track and output their current value.
2021-04-15 Update Jewel strip to match current size
    Clear all pixels between mode changes so that those that don't update
    every pixel on every pass can start fresh.
2021-04-16 Switch to the Bounce2 library for debouncing the buttons as it works much better than the simple logic I had before.
2021-04-16 Switch from NeoPixels to FastLED. Supports the Teensey 4.0, better features, faster performance, smaller code size, better support, more examples, etc.
    Add several demo modes from the FastLED samples at https://github.com/atuline/FastLED-Demos/.
    Remove unneeded debug code, move all debug strings into flash using the
    "F()" macro as we are running out of space.
2021-04-16 Add code to prevent attempting to address LEDs that are outside the number of LEDs in a strip. Remove boring Rainbow mode.
2021-04-19 Update KaleidoscopeLookupTable as it had a few bugs.
    Switch to using CRGB instead of uint32_t anywhere possible so we can
    leverage all the HSV and color helper functions in FastLED.
    Rename NUM_STRIPS and NUM_LEDS_PER_STRIP to match better with FastLED
    'standards' to make porting effects over easier.
    Update some of the demos to make them 'kaleidoscopic'
    Remove RTC clock as it is buggy (hangs after a few hours) and will be
    replaces with the teensy library.
    Remove seven-segment.h until it is updated
2021-04-20 Big changes this commit. The code has been updated to run on the Teensy 4.0.
    I'm using VisualTeensy to generate a project for VSCode and tycommander
    to do the flash update.
    Not everything is ported over yet. Still need to do the photoresister,
    clock, and rotary encoders.
    Don't make changes to files in the 'lib' directory - they are copied
    over by VisualTeensy from the original source so any changes will be
    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
2021-04-21 Add back support for the rotary encoders.
    Output mode being switched to when pressing rotary encoder buttons.
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2021-04-23 Switch to using OctoWS2811 for parallel output on multiple strings/pins. FastLED's parallel support on Teensy 4.0 is apparently broken.
    Rewrite brightness logic so that the knob increment/decrements the brightness
    delta.
    Apply a gamma function so that the brightness better matches expectations.
    [main.cpp]
2021-04-23 Add 3d models for honeycomb structure.
    [Honeycomb-notched-prototype.stl, Honeycomb-notched.scad, Honeycomb-notched.stl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]
2021-04-25 Remove annoying compiler warning. Fix DEBUG code so that we can successfully compiles with it turned off.
    [main.cpp]
2021-04-28 Create 3d model of complete Kaleidoscope. Clean up 3d model of honeycomb
    [Honeycomb-notched-prototype.stl, Honeycomb-notched.scad, Honeycomb-notched.stl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]
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2021-04-30 Update the pins so that the encoder push button switches work on ESP32
2021-05-01 Switch to ESP32 based rotary encoder library and get brightness knob working again.
2021-05-02 Add OTA support using ElegantOTA as it uses the same ESPAsyncWebServer that ESPAsync_WiFiManager uses. I still can't connect to it however so it needs debugging.
    Added test code for the left encoder knob to ensure the wiring will work
    as prototyped.
2021-05-08 remove usage of pullup resistor and replace it with our own external resistor as the internal ones don't work
    [main.cpp]
2021-05-08 Add #ifdefs so that I can debug why OTA updates always crash. Turns out, FastLED.Show is the culprit. It must be doing something in an ISR that doesn't have the IRAM_ATTR attribute which tells the co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
    Starting Kaleidoscope on Node32sESPAsync_WiFiManager v1.8.1
    Connected. Local IP: 192.168.1.252
    OTA web server started.
    RealTimeClock.setup
    mode_kaleidoscope_screensaver
    Kaleidoscope.setup
    Guru Meditation Error: Core 1 panic'ed (Cache disabled but cached memory region accessed)
    Core 1 register dump:
    PC : 0x4014e4f0 PS : 0x00060034 A0 : 0x800810c0 A1 : 0x3ffc0040
    A2 : 0x3ffc1c18 A3 : 0x00000000 A4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
    [main.cpp]
2021-05-10 Add Philips Hue emulation for Alexa support. My test device is not currently being discovered by the Alexa app on my phone.
2021-05-11 Update the kaleidoscope to blend between frames to make a smoother transition and sense of motion.
    Switch to using the FastLED alpha blend function.
2021-05-14 refactor clock logic. Add (non-functional) prototype code to read timezone from settings.
2021-05-14 Collect the current timezone from the WiFi config portal and persist it as a setting. Use the persisted setting to initialize the timezone in the clock.
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2021-05-26 Add double reset detection. To reset the wifi configuration, reboot then reboot a second time within 10 seconds of the first. This will put the device in AP mode and open the WiFi Manager Config Port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
    [main.cpp]
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2021-05-30 Add new ESP32StateMachineEncoder to replace ESP32Encoder library. This new class uses a state machine to ensure you only count transitions that are valid state changes. It does a much better job of d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
    [ESP32StateMachineEncoder.cpp, main.cpp]
2021-06-12 fix #defines for ENCODER so you can toggle it separately. Needed for the emulator which can have a button but not rotary encoders.
    [Kaleidoscope.cpp, main.cpp]
2021-06-12 Update XYIndex to work for fixed wiring of LED strips.
    Add new mode_test() function to facilitate testing out the wiring of the LED strips.
    [main.cpp]
2021-06-13 Update drawPixel6LookupTable to match corrected wiring of LED strips.
    [Kaleidoscope.cpp]
2021-06-15 fix bug in drawPaletteFrame that reversed the row and column
    [Kaleidoscope.cpp]
2021-06-19 Enabled left rotary knob to control the speed of the Kaleidoscope when in screen saver mode. Limit the range from zero delay (as fast as possible) to 1000 ms between frames.
    Add a fps counter to debug mode so we can view the impact of changes to
    the render code.
    Remove the broken sawtooth mode.
    [Kaleidoscope.cpp, main.cpp]
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2021-06-23 Change ESP32StateMachineEncoder to better emulate ESP32Encoder to make switching between them easier. I've found that with noisy rotary encoders, ESP32Encoder tends to catch all turns of the dial but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
    ESP32StateMachineEncoder on the other hand, will igore/miss these invalid
    turns. I've found that not having the knob respond is easier to understand
    and correct than having it return bogus events. For now, I'll stick with
    ESP32StateMachineEncoder.
    Update the pins used for the right encoder to utilize those that are
    truely general purpose IO pins (those with fewer caviats).
    Update the Kaleidoscope di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
    [ESP32StateMachineEncoder.cpp, Kaleidoscope.cpp, main.cpp]
2021-06-28 Add XY"DistortionWaves.cpp/h that I missed in the earlier commit.
    Update the rotary encoder switch initialization so that it doesn't
    attempt to turn on the internal pull up resistors as the KY-040 ones
    were using already contain 10k-Ohm pull up resisters.
    [main.cpp]
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2021-09-03 Update scad and stl files used to 3D print the Honeycomb structure.
    [Honeycomb.scad, Honeycomb.stl, Kaleidoscope.scad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]
2021-09-03 Add EasyEDA files used to create and order PCB.
    [BOM_PCB_ESP32 Kaleidoscope_2021-08-24.csv, OBJ_PCB_ESP32 Kaleidoscope.obj, PickAndPlace_PCB_ESP32 Kaleidoscope_2021-08-24.csv]
2021-09-07 Add XY fire mode
    [Honeycomb.scad, Honeycomb.stl, Kaleidoscope.scad]
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2021-09-08 turn off adding darkness to kaleidoscop using qsuba so that clock is more distinct
    fix up a bunch of errors in displaynumbers.cpp so that the numbers actually display correctly
    [Kaleidoscope.cpp]
2021-09-12 Update 3D model for honeycomb to make interior walls 1.6mm thick and exterior walls 0.8 thick. This is a good compromise that we can actually print (the 3D printer has a resolution of 0.4mm) but keep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
    [Honeycomb.stl, Kaleidoscope.scad]
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2021-09-14 Fix bug in web server code that handled HTTP_PUT/putSettings. putSettings now correctly parses the JSON object and returns a 200/"OK" response.
    [main.cpp]
2021-09-14 Remove the Espalexa library as it doesn't work with the Philips Hue stuff Remove the Adafruit GFX and FastLED NeoMatrix libraries as we aren't using them Switch to drawing anti aliased lines for the 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
    [main.cpp]
2021-09-15 switch color on displayHands to fixed color as it already does alpha blending as part of the antialiasing
2021-09-15 The OS updated last night which exposed some threading issues with the REST APIs. Change the logic to save any settings changes that come via the asyncronous REST API call (apparently on core 0) and 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
    [main.cpp]
2021-09-15 Add kaleidoscope draw styles to REST API. Fix bug in net settings where it overwrote the interactive settings.
    [Kaleidoscope.cpp, main.cpp]
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2021-09-21 Fix bug where the kaleidoscope didn't redraw when coming back from settings the speed or brighness.
    Add reference to where the analog clock source came from.
    [Kaleidoscope.cpp]
2021-09-25 Fix two bugs with the distortion waves. The first was that not all of the LEDs were getting the gamma correction needed. The second was that the optimization to not compute pixels that won't actually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
2021-09-29 update scad model to better reflect how I expect to build the wooden frame
    [Kaleidoscope.scad]
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2021-09-29 Clean up #defines so we can build/run it again on wokwi Fix PROGMEM usages so it runs on Arduino Mega (ESP32 ignores them) Archive all unused modes in an 'unused' folder.
    [main.cpp]
2021-10-02 Update the kaleidoscope color pallette logic so that it can have an array of color pallettes instead of a single color palette. It is setup to dynamically switches between on a timed basis (currently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
    I may want to pause this action when interacting manually with the kaleidoscope
    so that it doesn't change colors while you are manipulating the disks.
    [Kaleidoscope.cpp]
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2021-10-06 Update 3d model
    [Kaleidoscope.scad, Kaleidoscope.stl]
2021-10-06 Fix a few bugs and update the movement logic in the snake game.
    GlassDisk.cpp - fix debug palette for TestDisk
    Kaleidoscope.cpp - change kaleidoscope color palette's to ever 5 minutes so that motion of the disk is more apparent
    main.cpp - move starting debug message out of WIFI section
    XY.cpp - fix off by one bug when testing for out of bounds
    XYsnake.cpp + Snake.cpp/h- update movement to use a single knob that just changes your direction left or right to make it easier to play
    [Kaleidoscope.cpp, main.cpp]
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2022-02-01 Rewrite the weather module to utilize the AsyncHTTPRequest_Generic library so that fetching the weather is asynchronous. This prevents the UI from blocking when we make the request for the weather or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
    [Kaleidoscope.cpp, main.cpp]
2022-10-03 Switch to ESP32Encoder as ESP32StateMachineEncoder isn't working correctly.
    Remove last vestages of Arduino Mega support
    [ESP32StateMachineEncoder.cpp, main.cpp]
2022-10-30 Update to latest version of khoih-prog/ESPAsync_WiFiManager @ 1.15.1
    ; BUG! BUG! BUG!
    ;
    ; For some reason, Platform.IO doesn't get the current version of
    ; devyte/ESPAsyncDNSServer as per what is on GitHub. To work around
    ; this, I copy/pasted the correct code from GitHub into
    ; .pio/libdeps/ESPAsyncDNSServer/src/
    ;
    ; BUG! BUG! BUG!
    [main.cpp]
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2022-11-07 Fix longtime crashing bug by switching from StaticJsonDocument to DynamicJsonDocument in any async REST API requests.
    Add first itteration of web ui. Index.html is only used to simplify editing with standard tools.
    It is then copy/pasted into WebUI.cpp to simplify getting it into the image.
    This version mostly uses the older/compatible with more browsers XMLHttpRequest instead of the
    newer 'better' fetch() API.
    [Kaleidoscope.cpp, main.cpp, render.h]
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2022-11-11 Move wifi config/connect/drd logic into WiFiHelpers.c/h
    Fix the TIME #ifdefs so we can turn it off and still build
    Move mode_test into kaleidoscope
    [Kaleidoscope.cpp, main.cpp]
2022-11-17 Fix the crashing bug that sent us into the config portal on every boot. AsyncDNSServer scope needs to be globa as it is apparently used long after ESPAsync_WiFiManager is done.
    Add debug settings to enable JTAG debugging via the ESP-Prog. While it works, mostly,
    it is slow and tends to crash a lot. :(
    Clean up DEBUG code in several palces so that we can build and run with DEBUG turned on.
    Unfortunately, we can't do this globally via platform.ini as the OS/WiFi/??? stack is unstable when DEBUG is on.
    [main.cpp]
2022-11-30 Tighten up vertical spacing so it all fits on my Pixel
2022-12-10 When WiFi is actively transmitting/receiving data, the FastLED.show() command tends to crash or hang the main 'loop()' thread. This is because the FastLed library disables interrupts during calls to 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
    To fix this correctly requires us to switch to a different type of LED
    that doesn't require such tight timing loops to update or to switch to a
    different processor that has better hardware than the ESP32. Neither of
    these options are great as they both require a redesigned PCB so I'll
    try to minimze the conflict using a semaphore.
    While this will solve the conflicts for the WiFi calls that originate
    from the Kaleid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
    [main.cpp]
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2023-01-19 Add a debug configuration to the build file that supports JTAG debugging Update the rendering of the analog clock to make it more readable. Shorted the hour hand and turn off the second hand complete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
    [Kaleidoscope.cpp, main.cpp, modes.cpp]
2023-01-19 Work around bug in runtime that fails to initialize global variables in the correct order. Refactor variable names to be consistenly camel case. Refactor clock face to utilize a look up table.
    [Kaleidoscope.cpp]
2024-09-17 Add missing EasyEDA Pro project file for PCB
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2025-01-20 Revert how the web UI is provided as reading files from the SPIFFS file system as it causes random crashes in spite of setting FASTLED_ESP32_FLASH_LOCK. This also makes the WebUI page load much faste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
    Fixed a bug in index.html where the settings may have been retrieved before
    the async REST calls to retrieve the mods, faces, and drawStyles returned
    and added their contents to the dropdown controls. This could result in the
    UI not properly reflecting the current state.
    [main.cpp]
2025-01-21 Call ElegantOTA.loop(); so that an upgrade can reboot the ESP32 after it completes the upgrade.
2025-01-23 Minor cleanup in my attempt to get the web server to stop returning 500 errors after running overnight.
    [main.cpp]
2026-06-10 Fairly significant update to the libraries used in the project. The main motivation was to move to current/supported libraries, but also to enable OTA updates with a single APP partition.
    Update all libraries to current versions
    Switch to using the new fork of the ESP async libraries ESP32Async (AsyncTCP and ESPAsyncWebServer)
    Switch from ESPAsyncWiFiManager to MycilaESPConnect. This provides a better captive portal to enable configuring WiFi settings.
    Switch from ESP_DoubleResetDetector + ElegantOTA to MycilaSafeBoot. This has a simple, clean UI and allows OTA upgrades with a single APP partition (debug builds no longer fit with the old 2 partition OTA libraries).
    Start using the esp_random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
    [partitions-4MB-safeboot.csv]
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2026-08-05 Fix a bug when saving/restoring the rotary values.
    Fix a bug where pressing the power button on the WebUI that would blank
    the screen but still draw the clock. This was due to the fact that the
    kaleidoscope mode can be set asynchronously.
    [main.cpp, modes.cpp]
2026-09-17 Delay rtc_setup() until we have successfully connected.
    Add logic to asyncronously find your current Latitude/Longitude from your IP
    address once you are connected. This is used to determine dawn/dusk at your
    location and automatically dim the brightness.
    Add a double reset detector. If the machine is reset within 10 seconds of booting,
    it will reboot into the "safeboot" parition so that you can flash a new image.
    Fix RealTimeClock.cpp so that debug builds will report when NTP time is synchronized.
    Make safeboot.py more robust as it was timing out after rebooting into the safeboot partition.
    Turn off MycilaESPConnect logging in release builds.
    [main.cpp]
